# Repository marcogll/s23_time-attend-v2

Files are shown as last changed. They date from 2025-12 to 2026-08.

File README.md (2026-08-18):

<p align="center">
  <a href="https://soul23.mx">
    <picture>
      <source
        media="(prefers-color-scheme: dark)"
        srcset="https://raw.githubusercontent.com/marcogll/mg_data_storage/refs/heads/main/soul23/logo/soul23_logo_wh.png">
      <source
        media="(prefers-color-scheme: light)"
        srcset="https://raw.githubusercontent.com/marcogll/mg_data_storage/refs/heads/main/soul23/logo/soul23_logo_blk.png">
      Soul:23
    </picture>
  </a>
</p>

<h1 align="center">S23 Time Attend V2</h1>

<p align="center">
  Sistema de control de asistencia y jornada — dispositivo IoT basado en ESP32-S3.
</p>

<p align="center">
  
  
  
</p>

---

## Description

Sistema de control de asistencia y jornada en hardware: Time & Attendance IoT device basado en ESP32-S3 con diagrama de conexión (pinout seguro), guía de inicio rápido y carga de firmware.

C++ con PlatformIO/Arduino.

## ⚡️ Características Destacadas

*   **🛡️ Robustez Industrial:**
    *   **NFC Watchdog:** Verificación cada 15s. Si el lector se congela, el sistema realiza un *Hard Reset* físico al módulo RC522 y fuerza la ganancia de antena al máximo.
    *   **Auto-Formato:** Gestión automática del sistema de archivos (`LittleFS`) si se detecta corrupción.
    *   **Anti-Bloqueo:** Uso de `ESP8266WebServer` síncrono y gestión de memoria optimizada (PROGMEM) para evitar reinicios por desbordamiento de pila.

*   **⚙️ Configuración Vía Web (Portal Cautivo):**
    *   No requiere editar código (`secrets.h`) para cambiar WiFi o URLs.
    *   Configura **SSID**, **Password**, **Webhook URL** y **Nombre del Dispositivo** (User-Agent) desde el navegador.

*   **🎮 Controles Físicos y Gestuales:**
    *   **Doble Reset (Double Tap):** Presiona el botón `RST` dos veces rápido para forzar el Modo Configuración sin abrir la carcasa.
    *   **Botón Físico:** Opción de forzar config manteniendo presionado el botón (GPIO 0 / Flash) al arrancar.

---

## 🚀 Guía de Inicio Rápido

### 1. Hardware Requerido
| Componente | Descripción |
| :--- | :--- |
| **NodeMCU v2/v3** | ESP8266 (ESP-12E) |
| **RC522** | Lector NFC (SPI) |
| **OLED 0.96"** | Pantalla SSD1306 (I2C) |
| **Buzzer** | Activo/Pasivo (3.3V) |
| **LED** | Indicador de estado |

### 2. Carga del Firmware
Usa el script automatizado para compilar y subir (requiere `arduino-cli`):
```bash
./compile_and_upload.sh
```

### 3. Configuración Inicial
1.  Al encender por primera vez, el dispositivo creará una red WiFi llamada:
    *   **SSID:** `Soul23`
    *   **Password:** `1234567890`
2.  Conéctate con tu móvil o PC.
3.  Accede a `http://192.168.4.1` en tu navegador.
4.  Ingresa los datos:
    *   **SSID / Password:** Tu red WiFi local.
    *   **Webhook URL:** Endpoint donde recibirás los registros (ej. `https://api.tuempresa.com/asistencia`).
    *   **Nombre del Dispositivo:** Identificador único (se envía como `User-Agent` y en el JSON).
5.  Dale a "Guardar y Reiniciar". ¡Listo!

---

## 🔌 Diagrama de Conexión (Pinout Seguro)

Este pinout evita conflictos con el proceso de arranque (Boot) del ESP8266.

| RC522 | NodeMCU | GPIO | Notas |
| :--- | :--- | :--- | :--- |
| **SDA (SS)** | D8 | GPIO15 | Pull-down interno |
| **SCK** | D5 | GPIO14 | SPI Clock |
| **MOSI** | D7 | GPIO13 | SPI MOSI |
| **MISO** | D6 | GPIO12 | SPI MISO |
| **RST** | D0 | GPIO16 | **CRÍTICO:** Usado para Hard Reset del lector |
| **3.3V** | 3V3 | - | ⚠️ No usar 5V |
| **GND** | GND | - | - |

| Periférico | NodeMCU | GPIO | Notas |
| :--- | :--- | :--- | :--- |
| **OLED SDA** | D2 | GPIO4 | I2C Data |
| **OLED SCL** | D1 | GPIO5 | I2C Clock |
| **Buzzer** | D4 | GPIO2 | Inicializado tarde en setup() |
| **LED / Botón** | D3 | GPIO0 | Flash Button (Pull-up) |

---

## 🧠 Funcionamiento del Watchdog NFC

El lector RC522 es propenso a congelarse por interferencia electromagnética. Este firmware implementa una solución de 3 capas:

1.  **Monitorización:** Cada 15 segundos se consulta la versión del firmware del chip RC522.
2.  **Detección:** Si responde `0x00` o `0xFF`, se considera fallo.
3.  **Recuperación:**
    *   Se pone el pin `RST` (D0) en `LOW` por 50ms (corte de energía lógico).
    *   Se restaura a `HIGH`.
    *   Se re-inicializa la librería y se fuerza la ganancia de antena a `Max (48dB)`.

---

## 📡 Payloads

### Entrada (En Tarjeta NFC)
El tag debe contener un registro NDEF con un JSON válido:
```json
{
  "name": "Ana Lopez",
  "num_emp": "EMP001",
  "sucursal": "Centro",
  "telegram_id": "12345"
}
```

### Salida (Webhook POST)
El dispositivo envía este JSON al servidor:
```json
{
  "uuid": "AbC123XyZ",
  "timestamp": 1703435600,
  "datetime_utc": "2025-12-24T12:00:00Z",
  "date": "2025-12-24",
  "num_empleado": "EMP001",
  "name": "Ana Lopez",
  "branch": "Centro",
  "telegram_id": "12345"
}
```
*Headers:* `User-Agent`: (Nombre configurado en el portal)

---

## 🗺️ Roadmap de Desarrollo

### 📍 Fase 1: Optimización de Transmisión (Corto Plazo)
*   **Payload Base64:** Migrar el formato de envío de JSON plano a su equivalente codificado en **Base64**. Esto mejorará la integridad de los datos y facilitará el manejo de caracteres especiales en el transporte HTTP.

### 📍 Fase 2: Persistencia Offline (Medio Plazo)
*   **Lector MicroSD:** Integración de hardware para almacenamiento local mediante bus SPI.
*   **Sincronización Inteligente:** 
    *   Guardado automático de registros en la MicroSD cuando falla la conexión WiFi/Internet.
    *   Lógica de "Checkpoint": Al recuperar la conexión, el dispositivo verificará cuál fue el último registro recibido por el servidor y enviará en ráfaga los datos pendientes para garantizar **cero pérdida de información**.

### 📍 Fase 3: Modernización de Hardware (Investigación)
*   **Soporte para Apple/Google Wallet:** Investigación y prototipado con lectores que soporten protocolos **NFC VAS (Apple)** y **Smart Tap (Google)**. El objetivo es permitir que los empleados usen sus pases digitales en el móvil en lugar de tarjetas físicas, mejorando la seguridad y la experiencia de usuario.

---

## 📄 Licencia
MIT License.

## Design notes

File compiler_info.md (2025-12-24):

# 🔧 Guía de Compilación y Carga del Firmware

Esta guía te ayudará a compilar, cargar y monitorear el firmware del checador NFC en tu ESP8266 NodeMCU.

---

## 🚀 Método Rápido (Script Automático)

El proyecto incluye un script automatizado que realiza todo el proceso en un solo comando:

```bash
./compile_and_upload.sh
```

### ✨ Características del Script

#### 1. **Verificación de Estado del Dispositivo** 🔌
- ✅ Detecta automáticamente si el ESP8266 está conectado
- ✅ Muestra información detallada del puerto y tipo de placa
- ✅ Detecta automáticamente el puerto si el configurado no está disponible
- ✅ Verifica el estado antes de cada operación crítica

#### 2. **Barras de Progreso y Spinners** 📊
- ✅ Spinner animado durante la compilación
- ✅ Indicadores de progreso durante la carga del firmware
- ✅ Etapas visuales: "Iniciando", "Escribiendo", "Verificando", "Completando"
- ✅ Feedback visual claro en cada paso

#### 3. **Interfaz Mejorada** 🎨
- ✅ Encabezado visual con bordes
- ✅ Colores diferenciados para cada tipo de mensaje
- ✅ Indicadores de progreso paso a paso [1/4], [2/4], etc.
- ✅ Mensajes de error más descriptivos con sugerencias

#### 4. **Detección Automática** 🔍
- ✅ Busca automáticamente dispositivos disponibles si el puerto configurado no funciona
- ✅ Pregunta al usuario si desea usar el puerto detectado
- ✅ Muestra todos los puertos disponibles si no encuentra ninguno

### 📋 Ejemplo de Salida del Script

```
╔══════════════════════════════════════════════════════════╗
║     Checador NFC - Compilación y Carga Automática      ║
╚══════════════════════════════════════════════════════════╝

[0/4] Verificando configuración...
✅ secrets.h encontrado

[1/4] Verificando conexión del dispositivo...
   Puerto configurado: /dev/ttyUSB0
   Estado: ✅ Conectado (NodeMCU 1.0)
   Puerto seleccionado: /dev/ttyUSB0

[2/4] Compilando el sketch...
   FQBN: esp8266:esp8266:nodemcuv2
   Sketch: soul23_time_attendance.ino
   [|] Compilando... |  ← Spinner animado
   [✓] Compilación completada
✅ Compilación exitosa

[3/4] Cargando firmware al dispositivo...
   Puerto: /dev/ttyUSB0
   Estado: ✅ Conectado (NodeMCU 1.0)
   [|] Escribiendo... |  ← Spinner con etapas
   [✓] Carga completada
✅ Firmware cargado exitosamente

[4/4] Abriendo monitor serial...
   Puerto: /dev/ttyUSB0
   Baud rate: 115200
━━━━━━━━━━━━━━━━━━━━━━━━━━━━━━━━━━━━━━━━━━━━━━━━━━━━━━━━━━━━━━━━
   Monitor Serial (Presiona Ctrl+C para salir)
━━━━━━━━━━━━━━━━━━━━━━━━━━━━━━━━━━━━━━━━━━━━━━━━━━━━━━━━━━━━━━━━
```

### 🛠️ Personalización del Script

Puedes modificar estas variables al inicio del script `compile_and_upload.sh`:

```bash
PORT="/dev/ttyUSB0"                    # Puerto del dispositivo
FQBN="esp8266:esp8266:nodemcuv2"       # Tipo de placa
BAUD_RATE="115200"                     # Velocidad del monitor serial
```

---

## 🔧 Comandos Individuales

Si prefieres ejecutar los comandos manualmente o necesitas más control:

### 1. Verificar puertos disponibles

```bash
arduino-cli board list
```

### 2. Compilar el sketch

```bash
arduino-cli compile --fqbn esp8266:esp8266:nodemcuv2 soul23_time_attendance.ino
```

**Nota:** El FQBN `esp8266:esp8266:nodemcuv2` es para NodeMCU 1.0 (ESP-12E Module).

### 3. Cargar al dispositivo

```bash
arduino-cli upload -p /dev/ttyUSB0 --fqbn esp8266:esp8266:nodemcuv2 soul23_time_attendance.ino
```

**⚠️ Importante:** Reemplaza `/dev/ttyUSB0` con el puerto correcto de tu dispositivo (verifica con `arduino-cli board list`)

### 4. Abrir monitor serial

```bash
arduino-cli monitor -p /dev/ttyUSB0 --config baudrate=115200
```

**Para salir del monitor:** Presiona `Ctrl+C`

### 5. Compilar sin cargar (solo verificar errores)

```bash
arduino-cli compile --fqbn esp8266:esp8266:nodemcuv2 soul23_time_attendance.ino
```

### 6. Ver información detallada de compilación

```bash
arduino-cli compile --fqbn esp8266:esp8266:nodemcuv2 --verbose soul23_time_attendance.ino
```

### 7. Limpiar archivos de compilación

```bash
rm -rf build/
```

---

## 📦 Instalación de Dependencias

### Instalar Core de ESP8266

```bash
arduino-cli core install esp8266:esp8266
```

### Instalar Librerías Necesarias

```bash
# Librerías principales
arduino-cli lib install "MFRC522"
arduino-cli lib install "Adafruit SSD1306"
arduino-cli lib install "Adafruit GFX Library"
arduino-cli lib install "ArduinoJson"
arduino-cli lib install "Time"
```

---

## 🔍 Verificar Instalación

### Ver librerías instaladas

```bash
arduino-cli lib list
```

### Ver cores instalados

```bash
arduino-cli core list
```

### Verificar FQBN correcto

```bash
arduino-cli board listall | grep -i nodemcu
```

Salida esperada:
```
NodeMCU 0.9 (ESP-12 Module)                 esp8266:esp8266:nodemcu
NodeMCU 1.0 (ESP-12E Module)                esp8266:esp8266:nodemcuv2
```

---

## 🐛 Solución de Problemas

### Error: "No se encuentra secrets.h"

```bash
cp secrets.h.example secrets.h
# Luego edita secrets.h con tus credenciales
```

### Error: "Puerto no encontrado"

1. Verifica que el ESP8266 esté conectado:
   ```bash
   arduino-cli board list
   ```

2. Si no aparece, verifica permisos:
   ```bash
   sudo usermod -a -G dialout $USER
   ```
   Luego reinicia sesión o ejecuta:
   ```bash
   newgrp dialout
   ```

### Error: "FQBN no válido"

Verifica el modelo exacto de tu NodeMCU y ajusta el FQBN:
- **NodeMCU 1.0 (ESP-12E):** `esp8266:esp8266:nodemcuv2`
- **NodeMCU 0.9:** `esp8266:esp8266:nodemcu`

### Monitor serial no muestra datos

1. Verifica el baud rate (debe ser **115200**)
2. Presiona el botón **RESET** del ESP8266
3. Verifica que el puerto sea correcto
4. Asegúrate de que no haya otro programa usando el puerto serial

### Error durante la carga del firmware

1. **Desconecta el buzzer** temporalmente (desconecta el GND) durante la carga
2. Verifica que no haya otro programa usando el puerto
3. Presiona el botón **RESET** del ESP8266 antes de cargar
4. Si es necesario, mantén presionado el botón **BOOT** mientras cargas

### El script no encuentra el dispositivo

1. El script buscará automáticamente puertos disponibles
2. Si encuentra uno, te preguntará si deseas usarlo
3. Si no encuentra ninguno, verifica:
   - Que el cable USB esté bien conectado
   - Que el driver USB-Serial esté instalado
   - Que tengas permisos para acceder al puerto

---

## 💡 Tips y Mejores Prácticas

### Uso del Script Automático

- El script detecta automáticamente el puerto si el configurado no está disponible
- Los spinners muestran que el proceso está en ejecución
- Los mensajes de error incluyen sugerencias para solucionarlos
- El estado del dispositivo se verifica antes de cada operación crítica

### Desarrollo y Depuración

- **Mantén el monitor serial abierto** mientras pruebas para ver los mensajes de debug
- El código imprime información útil en Serial a 115200 baud
- Si cambias el código, solo necesitas recompilar y cargar (no necesitas cerrar el monitor)
- Para depuración, busca mensajes que empiezan con `--- Checador IOT (Public Version) ---`

### Flujo de Trabajo Recomendado

1. **Primera vez:**
   ```bash
   # Instalar dependencias
   arduino-cli core install esp8266:esp8266
   arduino-cli lib install "MFRC522" "Adafruit SSD1306" "Adafruit GFX Library" "ArduinoJson" "Time"
   
   # Configurar secrets.h
   cp secrets.h.example secrets.h
   # Editar secrets.h con tus credenciales
   
   # Compilar y cargar
   ./compile_and_upload.sh
   ```

2. **Desarrollo iterativo:**
   ```bash
   # Solo necesitas ejecutar el script
   ./compile_and_upload.sh
   ```

3. **Solo verificar compilación:**
   ```bash
   arduino-cli compile --fqbn esp8266:esp8266:nodemcuv2 soul23_time_attendance.ino
   ```

### Optimización

- Si tienes problemas de espacio, puedes limpiar archivos de compilación:
  ```bash
  rm -rf build/
  ```
- Para compilaciones más rápidas, el script ya optimiza el proceso automáticamente

---

## 📝 Resumen de Comandos Rápidos

```bash
# Método rápido (recomendado)
./compile_and_upload.sh

# Comandos individuales
arduino-cli board list                                    # Ver puertos
arduino-cli compile --fqbn esp8266:esp8266:nodemcuv2 soul23_time_attendance.ino
arduino-cli upload -p /dev/ttyUSB0 --fqbn esp8266:esp8266:nodemcuv2 soul23_time_attendance.ino
arduino-cli monitor -p /dev/ttyUSB0 --config baudrate=115200

# Verificación
arduino-cli lib list                                      # Ver librerías
arduino-cli core list                                     # Ver cores
arduino-cli board listall | grep -i nodemcu              # Ver placas disponibles
```

---

## 🎯 Próximos Pasos

Una vez que hayas compilado y cargado el firmware exitosamente:

1. ✅ Verifica que el dispositivo se conecte a WiFi
2. ✅ Revisa el monitor serial para confirmar la sincronización de tiempo
3. ✅ Prueba acercando una tarjeta NFC para verificar la lectura
4. ✅ Verifica que los registros se envíen correctamente al webhook

Para más información sobre el hardware y la configuración, consulta el [README.md](README.md).

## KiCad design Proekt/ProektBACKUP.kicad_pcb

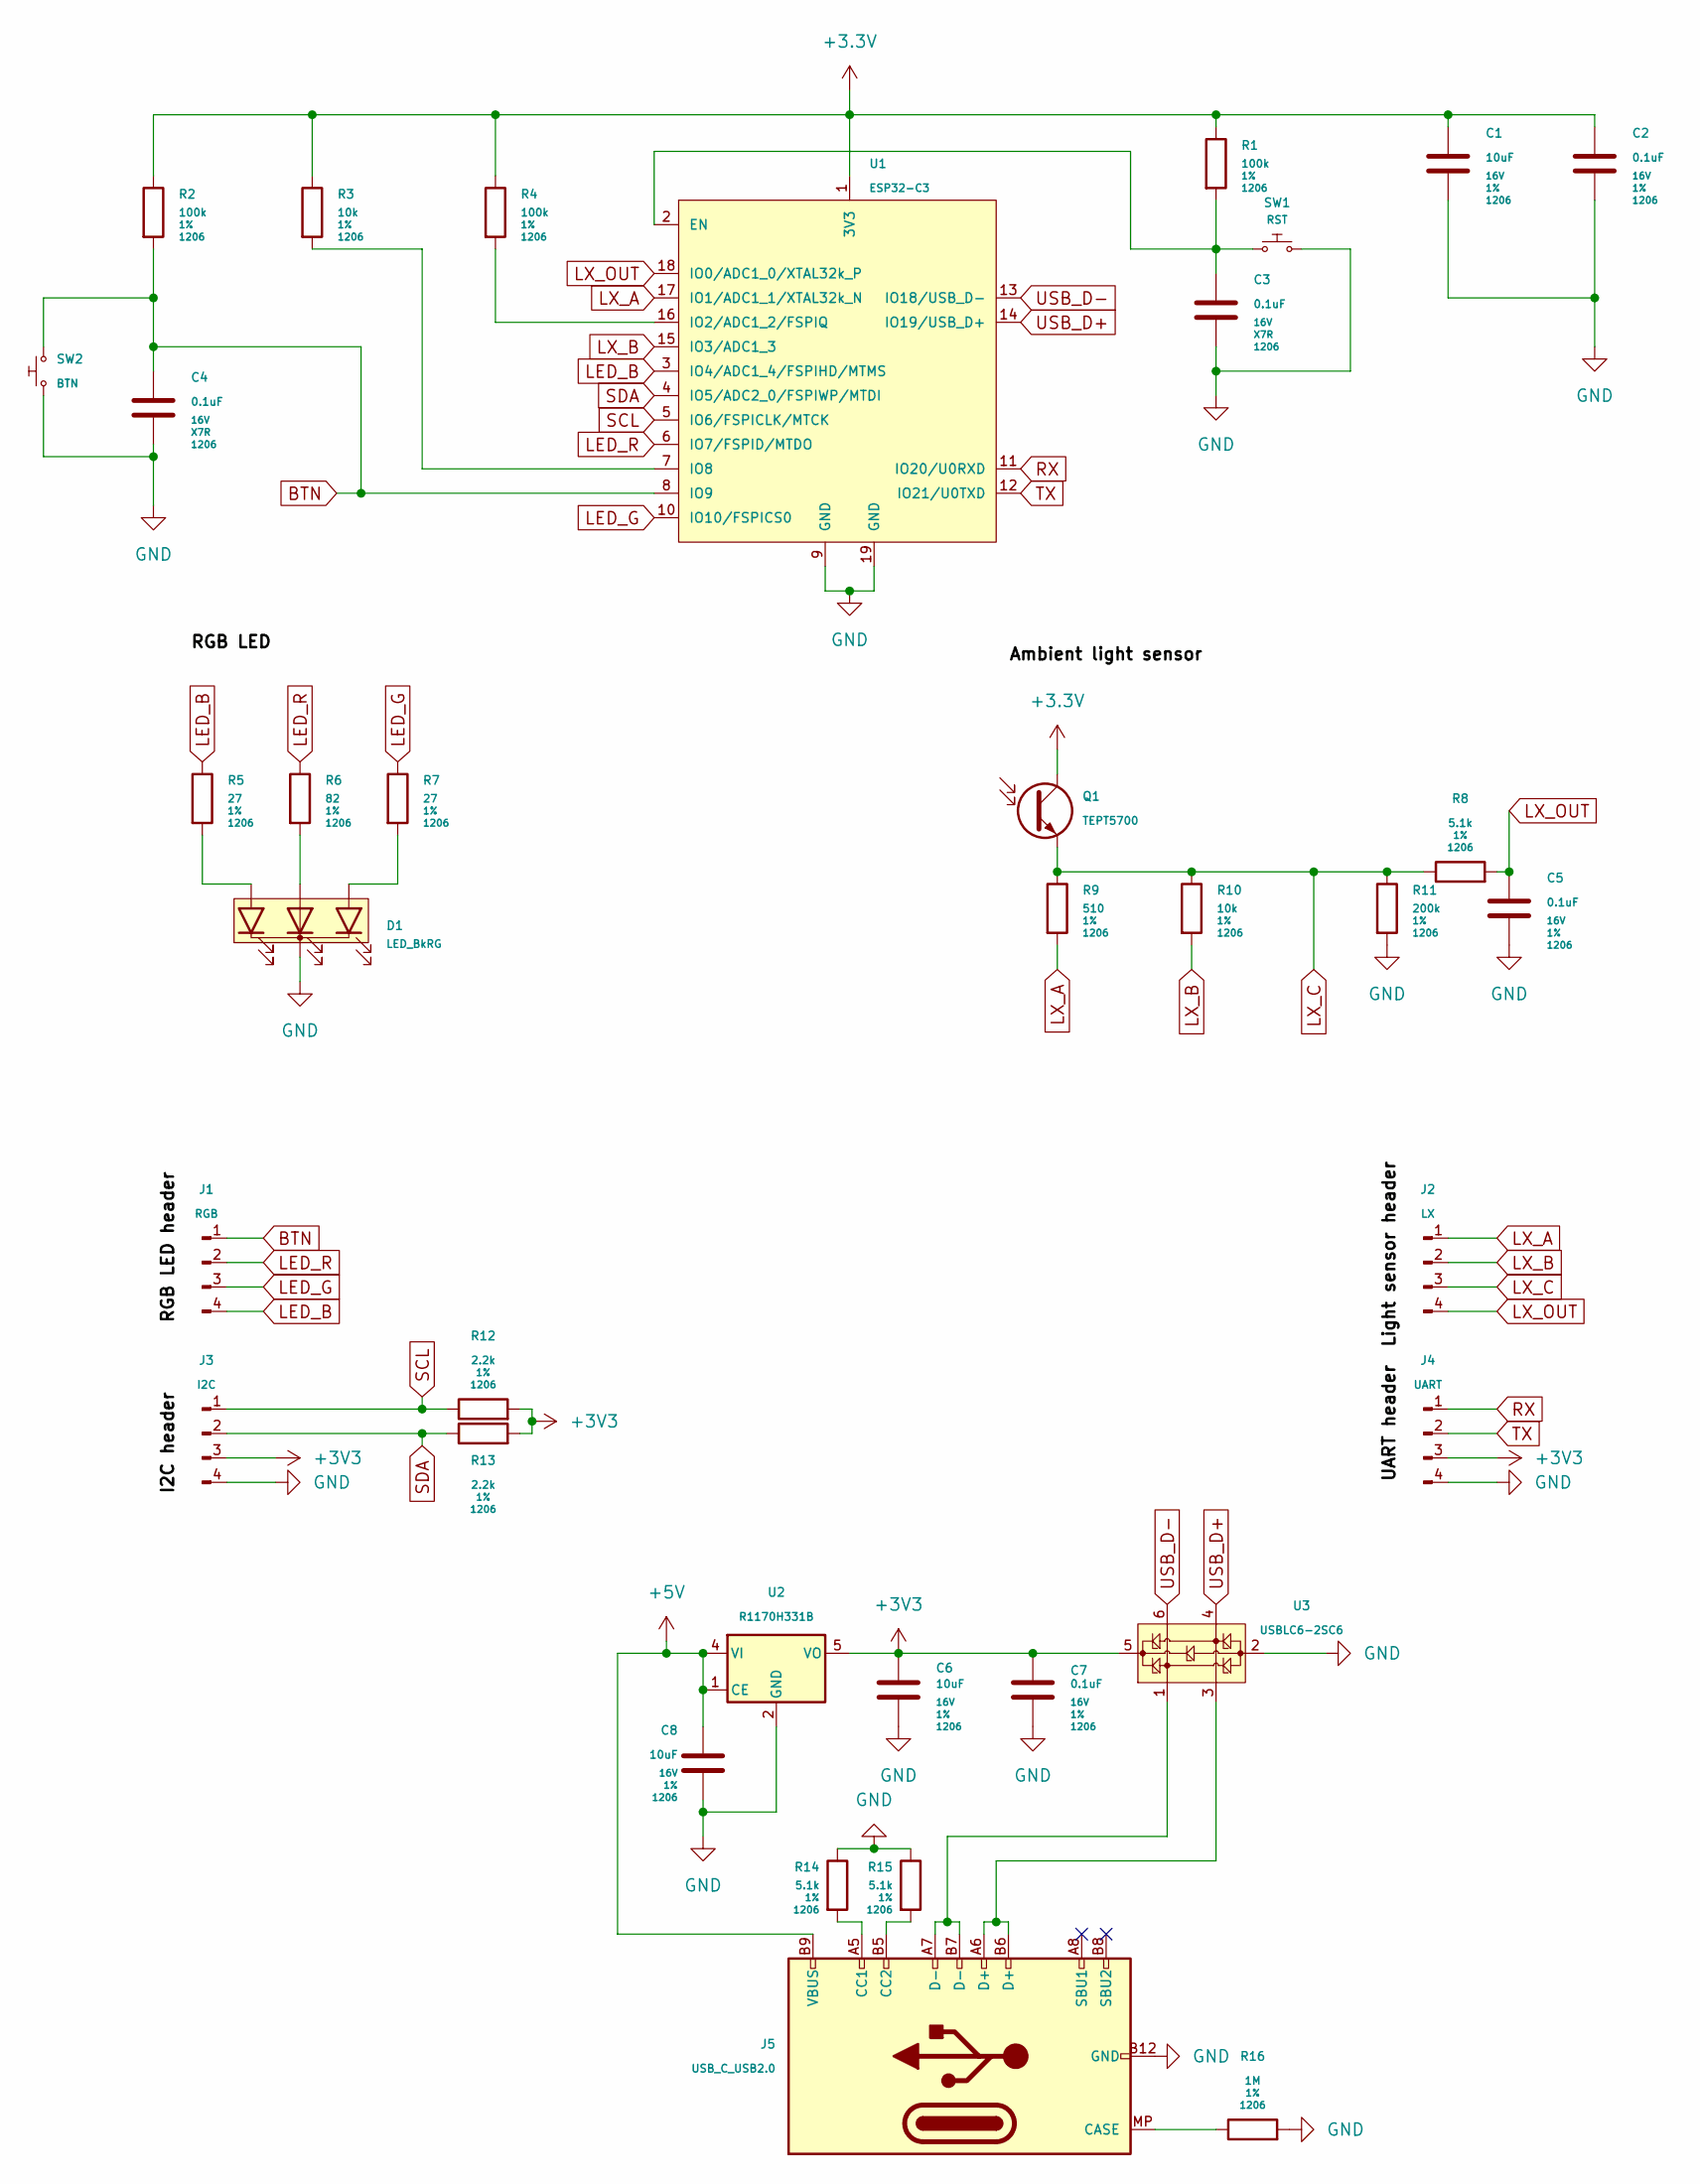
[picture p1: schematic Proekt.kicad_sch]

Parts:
C1, C6, C8: 10uF; C_1206_(3216); Voltage 16V; Tolerance 1%
C2, C5, C7: 0.1uF; C_1206_(3216); Voltage 16V; Tolerance 1%
C3, C4: 0.1uF; C_1206_(3216); Voltage 16V; Tolerance X7R
D1: LED_BkRG; LED_D5.0mm-4_RGB
J1: RGB; PinHeader_1x04_P2.54mm_Vertical
J2: LX; PinHeader_1x04_P2.54mm_Vertical
J3: I2C; PinHeader_1x04_P2.54mm_Vertical
J4: UART; PinHeader_1x04_P2.54mm_Vertical
J5: USB_C_USB2.0; USB-C_MOLEX-216990-0001
Q1: TEPT5700; PT_D5.0mm
R1, R2, R4: 100k; R_1206_(3216); Tolerance 1%
R3, R10: 10k; R_1206_(3216); Tolerance 1%
R5, R7: 27; R_1206_(3216); Tolerance 1%
R6: 82; R_1206_(3216); Tolerance 1%
R8, R14, R15: 5.1k; R_1206_(3216); Tolerance 1%
R9: 510; R_1206_(3216); Tolerance 1%
R11: 200k; R_1206_(3216); Tolerance 1%
R12, R13: 2.2k; R_1206_(3216); Tolerance 1%
R16: 1M; R_1206_(3216); Tolerance 1%
SW1: RST; SW_PUSH_6mm_SMD
SW2: BTN; SW_PUSH_6mm_SMD
U1: ESP32-C3; ESP32-C3-WROOM-02
U2: R1170H331B; SOT-89-5
U3: USBLC6-2SC6; SOT-23-6

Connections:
+5V: C8.1, J5.A4 (VBUS), J5.A9 (VBUS), J5.B4 (VBUS), J5.B9 (VBUS), U2.1 (CE), U2.4 (VI)
BTN: C4.1, J1.1, R2.2, SW2.COM, U1.8 (IO9)
GND: C1.2, C2.2, C3.1, C4.2, C5.2, C6.2, C7.2, C8.2, D1.K, J3.4, J4.4, J5.A1 (GND), J5.A12 (GND), J5.B1 (GND), J5.B12 (GND), R11.2, R14.1, R15.1, R16.2, SW1.COM, SW2.NO, U1.9 (GND), U1.19 (GND), U2.2 (GND), U3.2 (GND)
LED_B: J1.4, R5.1, U1.3 (IO4/ADC1_4/FSPIHD/MTMS)
LED_G: J1.3, R7.1, U1.10 (IO10/FSPICS0)
LED_R: J1.2, R6.1, U1.6 (IO7/FSPID/MTDO)
LX_A: J2.1, R9.2, U1.17 (IO1/ADC1_1/XTAL32k_N)
LX_B: J2.2, R10.2, U1.15 (IO3/ADC1_3)
LX_C: J2.3, Q1.E, R8.1, R9.1, R10.1, R11.1
LX_OUT: C5.1, J2.4, R8.2, U1.18 (IO0/ADC1_0/XTAL32k_P)
unnamed: D1.Ab (Ablue), R5.2
unnamed: D1.Ag (Agreen), R7.2
unnamed: D1.Ar (Ared), R6.2
unnamed: J5.MP (CASE), R16.1
unnamed: J5.A5 (CC1), R14.2
unnamed: J5.B5 (CC2), R15.2
unnamed: J5.A6 (D+), J5.B6 (D+), U3.3 (I/O2)
unnamed: J5.A7 (D-), J5.B7 (D-), U3.1 (I/O1)
unnamed: C3.2, R1.2, SW1.NO, U1.2 (EN)
unnamed: R4.2, U1.16 (IO2/ADC1_2/FSPIQ)
unnamed: R3.2, U1.7 (IO8)
RX: J4.1, U1.11 (IO20/U0RXD)
SCL: J3.1, R12.1, U1.5 (IO6/FSPICLK/MTCK)
SDA: J3.2, R13.1, U1.4 (IO5/ADC2_0/FSPIWP/MTDI)
TX: J4.2, U1.12 (IO21/U0TXD)
USB_D+: U1.14 (IO19/USB_D+), U3.4 (I/O2)
USB_D-: U1.13 (IO18/USB_D-), U3.6 (I/O1)

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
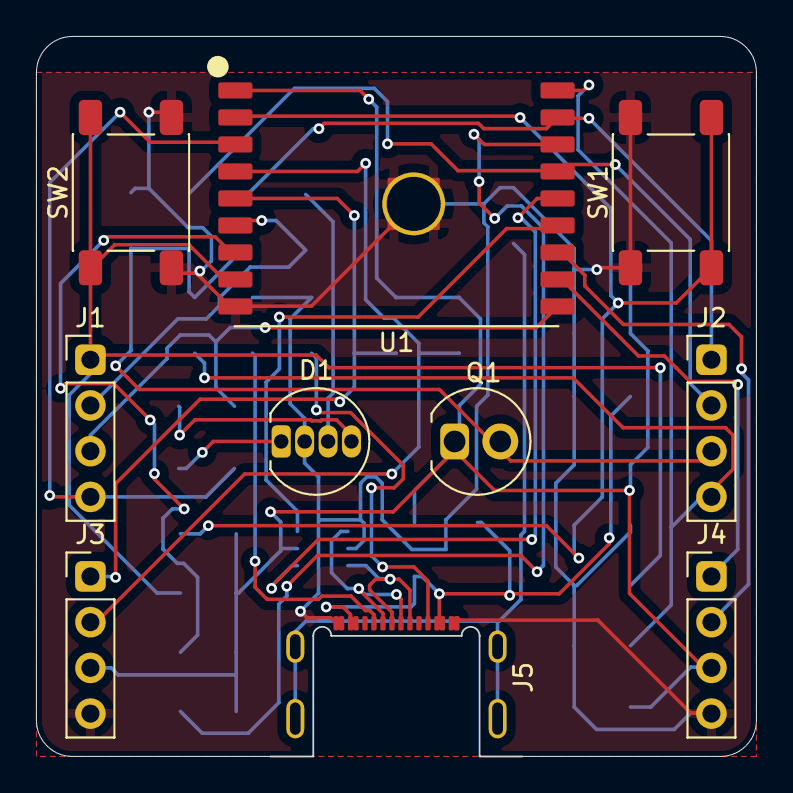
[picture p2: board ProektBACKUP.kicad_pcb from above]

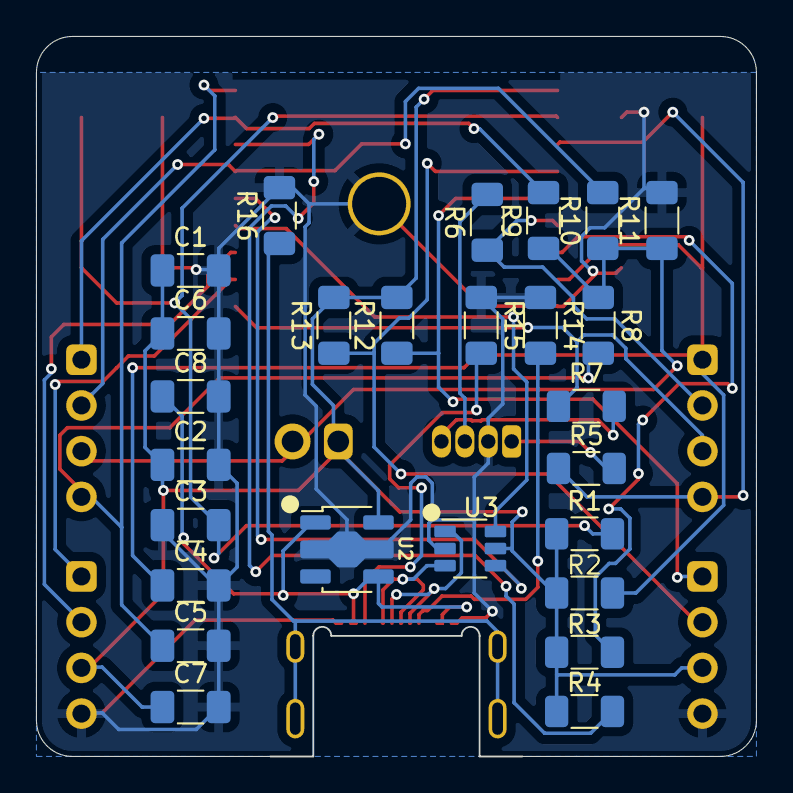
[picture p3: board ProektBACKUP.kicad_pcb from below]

Board: 2 copper layers, 40.0 x 40.0 mm, 36 parts (26 on the bottom side), 28 nets.

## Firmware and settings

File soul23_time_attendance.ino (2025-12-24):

#include <SPI.h>
#include <MFRC522.h>
#include <ESP8266WiFi.h>
#include <ESP8266HTTPClient.h>
#include <WiFiClientSecure.h>
#include <ArduinoJson.h>
#include <Wire.h>
#include <Adafruit_GFX.h>
#include <Adafruit_SSD1306.h>
#include <TimeLib.h> // Requiere instalar: arduino-cli lib install "Time"
#include <ESP8266WebServer.h>
#include <DNSServer.h>

#include "Config.h"

// Constantes globales de configuración
const char* timeServerUrl = "https://worldtimeapi.org/api/ip";
// const char* DEVICE_NAME = "Checador_Oficina_1"; // Eliminado, ahora es dinámico
const long timeZoneOffset = -21600;

// Intervalo de resincronización del reloj (1 hora)
const unsigned long syncInterval = 3600000; 

// ==========================================
// 🔌 PINES SEGUROS (NO INTERFIEREN CON BOOT)
// ==========================================
#define SS_PIN  D8  // GPIO 15
#define RST_PIN D0  // GPIO 16
#define OLED_SDA D2
#define OLED_SCL D1
#define LED_PIN  D3  // LED de estatus (GPIO 0) - Inicializado con pull-up para evitar problemas de boot
#define BUZZER_PIN D4 // Buzzer (GPIO 2) - ⚠️ IMPORTANTE: Inicializado MUY TARDE en setup() para evitar problemas de boot

MFRC522 mfrc522(SS_PIN, RST_PIN);

#define SCREEN_WIDTH 128
#define SCREEN_HEIGHT 64
Adafruit_SSD1306 display(SCREEN_WIDTH, SCREEN_HEIGHT, &Wire, -1);

// Variables para el modo configuración
Config config;
ESP8266WebServer *server = nullptr;
DNSServer *dnsServer = nullptr;
bool configurationMode = false;
bool shouldRestart = false;

// Variables de control
unsigned long lastSyncTime = 0;
int lastMinuteDisplayed = -1;
bool hasError = false;
unsigned long lastBlinkTime = 0;
bool ledState = LOW;

// Control del Watchdog del Lector NFC
const unsigned long nfcCheckInterval = 15000; // 15 segundos para detección rápida de fallos
unsigned long lastNfcCheck = 0;


// ==========================================
// 📝 DECLARACIONES DE FUNCIONES
// ==========================================
void checkAndResetNFC();
void showStatus(String line1, String line2);
void syncTimeWithServer();
bool sendToWebhook(String uid, String name, String num_emp, String sucursal, String telegram_id);
void showClockScreen();
String getFormattedTime();
bool readCardData(byte *data, byte *length);
void processTag();
String generateUUID(byte length);
String getISO8601DateTime(time_t t);
String getFormattedDate();
void beep(int times, int duration);
void alarmSound();
void silenceBuzzer();
void updateStatusLED();
void scanI2C();
void startConfigurationMode();

// ==========================================
// 🚀 SETUP
// ==========================================
void setup() {
  Serial.println("\n--- Iniciando setup ---");
  // ⚠️ CRÍTICO: Inicializar GPIO 2 (BUZZER) PRIMERO para evitar ruido durante boot
  // GPIO 2 tiene pull-up interno que puede causar problemas con buzzer pasivo
  // Configurarlo como INPUT sin pull-up/pull-down para evitar interferencia
  pinMode(BUZZER_PIN, INPUT); // INPUT sin pull para evitar ruido durante boot
  delay(10); // Pequeña pausa para estabilizar
  
  // ⚠️ INICIALIZAR GPIO 0 (LED) CON PULL-UP para evitar problemas de boot
  // Si GPIO 0 está LOW durante boot, el ESP8266 entra en modo programación
  pinMode(LED_PIN, INPUT_PULLUP); // Primero como INPUT con pull-up interno
  delay(10); // Pequeña pausa para estabilizar
  
  Serial.begin(115200);
  delay(100);

  WiFi.persistent(false); // Evita la reconexión automática que causa conflictos

  Serial.println("\n\n--- Checador IOT (Public Version) ---");
  
  randomSeed(analogRead(A0));

  SPI.begin();
  Wire.begin(OLED_SDA, OLED_SCL);

  scanI2C();
  mfrc522.PCD_Init();
  mfrc522.PCD_DumpVersionToSerial();
  mfrc522.PCD_SetAntennaGain(mfrc522.RxGain_max); // 🚀 Maxima ganancia antena

  if(!display.begin(SSD1306_SWITCHCAPVCC, 0x3C)) {
    Serial.println(F("Intentando dirección OLED 0x3D..."));
    if(!display.begin(SSD1306_SWITCHCAPVCC, 0x3D)) {
      Serial.println(F("Error: No se encuentra OLED"));
      sos();
    }
  }
  display.clearDisplay();
  display.setTextColor(WHITE);
  display.dim(false);
  Serial.println("OLED inicializado y configurado.");

  if (!LittleFS.begin()) {
    Serial.println("LittleFS mount failed. Formatting...");
    if (LittleFS.format()) {
      Serial.println("LittleFS formatted successfully");
      if (LittleFS.begin()) {
        Serial.println("LittleFS mounted after format");
      } else {
        Serial.println("LittleFS mount failed after format");
      }
    } else {
      Serial.println("LittleFS format failed");
    }
  } else {
    Serial.println("LittleFS mounted successfully");
  }
  // --- Lógica de Doble Reset (Double Tap) ---
  uint32_t rtcMagic = 0;
  ESP.rtcUserMemoryRead(0, &rtcMagic, sizeof(rtcMagic));
  bool doubleResetDetected = (rtcMagic == 0x1A2B3C4D);

  // Armar el detector para el siguiente reset (se desarmará en loop después de 3s)
  rtcMagic = 0x1A2B3C4D;
  ESP.rtcUserMemoryWrite(0, &rtcMagic, sizeof(rtcMagic));

  // Verificar botón físico (Flash/D3) O Doble Reset
  bool forceConfigMode = (digitalRead(LED_PIN) == LOW) || doubleResetDetected;
  
  pinMode(LED_PIN, OUTPUT);
  digitalWrite(LED_PIN, LOW);

  Serial.print("Modo Config forzado: ");
  if (digitalRead(LED_PIN) == LOW) Serial.print("BOTON ");
  if (doubleResetDetected) Serial.print("DOBLE_RESET ");
  Serial.println(forceConfigMode ? "(SI)" : "(NO)");

  bool configLoaded = loadConfig(config);
  Serial.print("Configuración cargada exitosamente: ");
  Serial.println(configLoaded ? "Sí" : "No");

  if (configLoaded && !forceConfigMode) {
    showStatus("CONECTANDO", "WIFI...");
    WiFi.mode(WIFI_STA);
    WiFi.begin(config.ssid, config.password);

    int timeout = 0;
    while (WiFi.status() != WL_CONNECTED && timeout < 60) {
      delay(500); Serial.print("."); timeout++;
    }

    if (WiFi.status() == WL_CONNECTED) {
      showStatus("WIFI", "OK");
      delay(1000);
      configurationMode = false;
    } else {
      showStatus("ERROR WIFI", "MODO CONFIG");
      delay(2000);
      configurationMode = true;
    }
  } else {
    showStatus("HOLA!", "MODO CONFIG");
    delay(2000);
    configurationMode = true;
  }
  
  if (configurationMode) {
    startConfigurationMode();
  } else {
    syncTimeWithServer();
    Serial.println("Sistema Listo.");

    delay(100);
    pinMode(BUZZER_PIN, OUTPUT);
    digitalWrite(BUZZER_PIN, LOW);
    delay(50);
    digitalWrite(BUZZER_PIN, LOW);
    delay(10);
    digitalWrite(BUZZER_PIN, LOW);

    blinkLed(5, 200);
    digitalWrite(LED_PIN, LOW);
    silenceBuzzer();
  }
}

// ==========================================
// 🔄 LOOP PRINCIPAL
// ==========================================
void loop() {
  // Desarmar Doble Reset después de 3 segundos de funcionamiento estable
  static bool drDisarmed = false;
  if (!drDisarmed && millis() > 3000) {
      uint32_t rtcMagic = 0;
      ESP.rtcUserMemoryWrite(0, &rtcMagic, sizeof(rtcMagic));
      drDisarmed = true;
      // Serial.println("Double Reset: Desarmado"); // Opcional para debug
  }

  if (shouldRestart) {
    Serial.println(F("Reiniciando sistema..."));
    delay(2000);
    ESP.restart();
  }

  if (configurationMode) {
    if (dnsServer) dnsServer->processNextRequest();
    if (server) server->handleClient();
    delay(10);
  } else {
    checkAndResetNFC();

    if (timeStatus() == timeNotSet || (millis() - lastSyncTime > syncInterval)) {
      syncTimeWithServer();
    }

    if (minute() != lastMinuteDisplayed) {
      showClockScreen();
      lastMinuteDisplayed = minute();
    }

    if (mfrc522.PICC_IsNewCardPresent() && mfrc522.PICC_ReadCardSerial()) {
      processTag();
      lastMinuteDisplayed = -1;
    }

    silenceBuzzer();
    delay(50);
  }
}

// ==========================================
// 📋 LÓGICA DE PROCESAMIENTO
// ==========================================
void processTag() {
  String uid = "";
  for (byte i = 0; i < mfrc522.uid.size; i++) {
     uid += (mfrc522.uid.uidByte[i] < 0x10 ? "0" : "");
     uid += String(mfrc522.uid.uidByte[i], HEX);
  }
  uid.toUpperCase();

  byte buffer[128]; 
  byte bufferSize = sizeof(buffer);
  
  if (readCardData(buffer, &bufferSize)) {
    int jsonStart = -1;
    for (int i = 0; i < bufferSize; i++) { if (buffer[i] == '{') { jsonStart = i; break; } }

    if (jsonStart != -1) {
      DynamicJsonDocument docCard(512);
      DeserializationError error = deserializeJson(docCard, (const char*)(buffer + jsonStart));

      if (error) {
        showStatus("ERROR", "JSON ILEGIBLE");
        signalTemporaryError();
      } else {
        String name = docCard["name"];
        String num_emp = docCard["num_emp"];
        String sucursal = docCard["sucursal"];
        String telegram_id = docCard["telegram_id"];
        
        sendToWebhook(uid, name, num_emp, sucursal, telegram_id);
      }
    } else {
      showStatus("ERROR", "SIN JSON");
      signalTemporaryError();
    }
  } else {
    showStatus("ERROR", "LECTURA FALLO");
    signalTemporaryError();
  }

  mfrc522.PICC_HaltA();
  mfrc522.PCD_StopCrypto1();
  // El delay y el apagado del LED se manejan ahora en las funciones de señalización
}

// ==========================================
// 🚨 WATCHDOG DEL LECTOR NFC
// ==========================================
/**
 * @brief Verifica el estado del lector NFC y lo reinicia si no responde.
 * 
 * Se ejecuta periódicamente según 'nfcCheckInterval'. Lee el registro de versión
 * del chip MFRC522. Si devuelve 0x00 o 0xFF, asume que está colgado e intenta
 * reinicializarlo mediante un HARD RESET físico (Pin RST).
 */
void checkAndResetNFC() {
  if (millis() - lastNfcCheck > nfcCheckInterval) {
    // 1. Heartbeat check: Read Firmware Version
    byte v = mfrc522.PCD_ReadRegister(MFRC522::VersionReg);

    // Si la versión es 0x00 o 0xFF, la comunicación SPI o el módulo fallaron
    if (v == 0x00 || v == 0xFF) {
      Serial.println(F("NFC Watchdog: Lector NO responde. Ejecutando HARD RESET..."));

      // 2. Hard Reset Sequence (Physical Pin Toggle)
      // Forzamos el pin RST a LOW para reiniciar el chip físicamente
      pinMode(RST_PIN, OUTPUT);
      digitalWrite(RST_PIN, LOW);
      delay(50); // Mantener reset
      digitalWrite(RST_PIN, HIGH);
      delay(50); // Esperar a que el chip despierte

      // 3. Re-Inicializar Librería
      mfrc522.PCD_Init();
      delay(10);

      // 4. Boost Sensitivity (Max Gain) - Importante para estabilidad
      mfrc522.PCD_SetAntennaGain(mfrc522.RxGain_max);

      // 5. Verificar recuperación
      byte v_new = mfrc522.PCD_ReadRegister(MFRC522::VersionReg);
      if (v_new == 0x00 || v_new == 0xFF) {
         Serial.println(F("NFC Watchdog: FALLO. El lector sigue sin responder."));
      } else {
         Serial.print(F("NFC Watchdog: RECUPERADO. Versión: 0x"));
         Serial.println(v_new, HEX);
      }
    } 
    // Si responde bien, no hacemos nada para no interrumpir el flujo normal
    
    lastNfcCheck = millis();
  }
}

// ==========================================
// ☁️ RED Y LECTURA DE TARJETA
// ==========================================
/**
 * @brief Lee los datos almacenados en los bloques de la tarjeta MIFARE.
 * 
 * Intenta autenticarse con la clave por defecto (NFC Forum Key) y leer
 * los bloques 4 a 12 de la tarjeta.
 * 
 * @param data Puntero al buffer donde se guardarán los datos leídos.
 * @param length Puntero al tamaño del buffer (se actualiza con bytes leídos).
 * @return true Si la lectura fue exitosa.
 * @return false Si hubo error de autenticación o lectura.
 */
bool readCardData(byte *data, byte *length) {
  MFRC522::MIFARE_Key key;
  byte nfcForumKey[6] = {0xD3, 0xF7, 0xD3, 0xF7, 0xD3, 0xF7};
  memcpy(key.keyByte, nfcForumKey, 6);

  MFRC522::StatusCode status = mfrc522.PCD_Authenticate(MFRC522::PICC_CMD_MF_AUTH_KEY_A, 4, &key, &(mfrc522.uid));
  if (status != MFRC522::STATUS_OK) { return false; }
  
  delay(5);

  byte readBlock[18];
  byte index = 0;
  for (byte block = 4; block < 12; block++) {
    if (block % 4 == 3) {
      status = mfrc522.PCD_Authenticate(MFRC522::PICC_CMD_MF_AUTH_KEY_A, block + 1, &key, &(mfrc522.uid));
      if (status != MFRC522::STATUS_OK) break;
      continue;
    }
    byte size = sizeof(readBlock);
    status = mfrc522.MIFARE_Read(block, readBlock, &size);
    if (status != MFRC522::STATUS_OK) break;
    memcpy(&data[index], readBlock, 16);
    index += 16;
  }
  *length = index;
  return index > 0;
}

/**
 * @brief Sincroniza la hora interna del ESP8266 con un servidor NTP/API externo.
 * 
 * Realiza una petición HTTP GET a 'timeServerUrl' (WorldTimeAPI).
 * Parsea el JSON de respuesta y establece la hora del sistema usando 'TimeLib'.
 */
void syncTimeWithServer() {
  if (WiFi.status() != WL_CONNECTED) return;
  std::unique_ptr<WiFiClientSecure> client(new WiFiClientSecure);
  client->setInsecure();
  HTTPClient http;
  if (http.begin(*client, timeServerUrl)) {
    http.setTimeout(10000); // Timeout de 10 segundos para evitar resets por watchdog
    http.setUserAgent(config.deviceName);
    int httpCode = http.GET();
    if (httpCode == HTTP_CODE_OK) {
      DynamicJsonDocument doc(1024);
      deserializeJson(doc, http.getString());
      // Ajuste para el servidor de ejemplo worldtimeapi.org
      setTime(doc["unixtime"].as<unsigned long>() + timeZoneOffset); 
      lastSyncTime = millis();
    }
    http.end();
  }
}

/**
 * @brief Envía el registro de asistencia al Webhook configurado.
 * 
 * Construye un JSON con los datos del empleado y la tarjeta, y lo envía
 * mediante una petición HTTP POST segura (HTTPS).
 * 
 * @param uid UID de la tarjeta leída.
 * @param name Nombre del empleado.
 * @param num_emp Número de empleado.
 * @param sucursal Sucursal asignada.
 * @param telegram_id ID de Telegram para notificaciones.
 * @return true Si el envío fue exitoso (HTTP 2xx).
 * @return false Si hubo error en la conexión o respuesta.
 */
bool sendToWebhook(String uid, String name, String num_emp, String sucursal, String telegram_id) {
  if (timeStatus() == timeNotSet) {
    showStatus("ERROR", "SIN HORA");
    signalTemporaryError();
    return false;
  }
  
  std::unique_ptr<WiFiClientSecure> client(new WiFiClientSecure);
  client->setInsecure();
  HTTPClient http;
  
  unsigned long utcTimestamp = now() - timeZoneOffset;
  String uuid = generateUUID(11);
  String date = getFormattedDate();
  String datetime_utc = getISO8601DateTime(utcTimestamp);

  showStatus("ENVIANDO", "REGISTRO...");

  Serial.print("Webhook URL: "); Serial.println(config.webhookUrl);

  if (http.begin(*client, config.webhookUrl)) {
    http.setTimeout(15000); // Aumentar timeout a 15s
    http.setUserAgent(config.deviceName);
    http.addHeader("Content-Type", "application/json");

    DynamicJsonDocument doc(1024);
    JsonArray array = doc.to<JsonArray>();

    JsonObject obj = array.createNestedObject();
    obj["uuid"] = uuid;
    obj["timestamp"] = utcTimestamp;
    obj["datetime_utc"] = datetime_utc;
    obj["date"] = date;
    obj["num_empleado"] = num_emp;
    obj["name"] = name;
    obj["branch"] = sucursal;
    obj["telegram_id"] = telegram_id;

    String jsonPayload;
    serializeJson(doc, jsonPayload);
    Serial.print("Payload: "); Serial.println(jsonPayload); // Debug payload
    
    int httpResponseCode = http.POST(jsonPayload);
    Serial.print("HTTP Code: "); Serial.println(httpResponseCode); // Debug code

    if (httpResponseCode > 0) {
        String response = http.getString();
        Serial.println("Respuesta: " + response);
    } else {
        Serial.print("Error HTTP: ");
        Serial.println(http.errorToString(httpResponseCode));
    }

    if (httpResponseCode >= 200 && httpResponseCode < 300) {
      showStatus("HOLA :)", name);
      http.end();
      blinkLed(5, 200); // Éxito - Parpadeo de 5 veces (mismo comportamiento que boot)
      return true;
    } else {
      showStatus("ERROR", "AL ENVIAR");
      http.end();
      signalTemporaryError();
      return false;
    }
  }
  signalTemporaryError();
  return false;
}

// ==========================================
// 🔊 BUZZER Y LEDS
// ==========================================

void signalTemporaryError() {
  alarmSound();
  digitalWrite(LED_PIN, HIGH);
  delay(5000);
  digitalWrite(LED_PIN, LOW);
}

void blinkLed(int times, int duration) {
  for (int i = 0; i < times; i++) {
    digitalWrite(LED_PIN, HIGH);
    delay(duration);
    digitalWrite(LED_PIN, LOW);
    if (i < times - 1) delay(duration);
  }
}

void morseDot() {
  digitalWrite(LED_PIN, HIGH);
  delay(250);
  digitalWrite(LED_PIN, LOW);
  delay(250);
}

void morseDash() {
  digitalWrite(LED_PIN, HIGH);
  delay(750);
  digitalWrite(LED_PIN, LOW);
  delay(250);
}

void sos() {
  while(true) { // Bucle infinito para S.O.S.
    // SOS con la luz: ... --- ... (3 segundos)
    morseDot(); morseDot(); morseDot();
    delay(500);
    morseDash(); morseDash(); morseDash();
    delay(500);
    morseDot(); morseDot(); morseDot();
    delay(3000); // 3 segundos de SOS
    delay(10000); // Esperar 10 segundos antes de repetir
  }
}

void beep(int times, int duration) {
  // Asegurar que el pin esté configurado (por si se llama antes del setup completo)
  static bool buzzerInitialized = false;
  if (!buzzerInitialized) {
    pinMode(BUZZER_PIN, OUTPUT);
    digitalWrite(BUZZER_PIN, LOW);
    buzzerInitialized = true;
  }
  
  for (int i = 0; i < times; i++) {
    digitalWrite(BUZZER_PIN, HIGH);
    delay(duration);
    digitalWrite(BUZZER_PIN, LOW);
    if (i < times - 1) delay(duration / 2);
  }
  
  // Asegurar que el buzzer quede silenciado después de cada beep
  digitalWrite(BUZZER_PIN, LOW);
  delay(10); // Pequeña pausa para estabilizar
}

void alarmSound() {
  beep(3, 150); // 3 beeps cortos y rápidos para el error
  silenceBuzzer(); // Asegurar que quede silenciado después del error
}

void silenceBuzzer() {
  // Función para asegurar que el buzzer esté completamente silenciado
  // Útil para evitar ruido o interferencia electromagnética
  // Asegurar que el pin esté configurado como OUTPUT y en LOW
  pinMode(BUZZER_PIN, OUTPUT);
  digitalWrite(BUZZER_PIN, LOW);
}

// ==========================================
// 🖥️ PANTALLA Y UTILIDADES
// ==========================================
String generateUUID(byte length) {
  String randomString = "";
  const char charset[] = "ABCDEFGHIJKLMNOPQRSTUVWXYZabcdefghijklmnopqrstuvwxyz0123456789";
  for (byte i = 0; i < length; i++) {
    randomString += charset[random(sizeof(charset) - 1)];
  }
  return randomString;
}

String getISO8601DateTime(time_t t) {
  char buff[21];
  sprintf(buff, "%04d-%02d-%02dT%02d:%02d:%02dZ",
    year(t), month(t), day(t), hour(t), minute(t), second(t));
  return String(buff);
}

String getFormattedDate() {
  String dateStr = String(year()) + "-";
  if (month() < 10) dateStr += "0"; dateStr += String(month());
  dateStr += "-";
  if (day() < 10) dateStr += "0"; dateStr += String(day());
  return dateStr;
}

String getFormattedTime() {
  String timeStr = "";
  int h = hour(); int m = minute(); String ampm = "AM";
  if (h >= 12) { ampm = "PM"; if (h > 12) h -= 12; }
  if (h == 0) h = 12;
  if (h < 10) timeStr += " "; timeStr += String(h); timeStr += ":";
  if (m < 10) timeStr += "0"; timeStr += String(m); timeStr += " " + ampm;
  return timeStr;
}

void showClockScreen() {
  display.clearDisplay();
  display.setTextSize(1); display.setCursor(0, 0); display.println(F("CHECADOR"));
  display.setTextSize(2); display.setCursor(10, 25); 
  if (timeStatus() != timeNotSet) { display.println(getFormattedTime()); }
  else { display.println("--:--"); }
  display.setTextSize(1); display.setCursor(0, 55); display.println(F("ACERQUE TARJETA..."));
  display.display();
}

void showStatus(String line1, String line2) {
  display.clearDisplay();
  display.setTextSize(2); display.setCursor(0, 10); display.println(line1);
  if(line2.length() > 8) display.setTextSize(1); else display.setTextSize(2);
  display.setCursor(0, 35); display.println(line2);
  display.display();
}

void scanI2C() {
  byte error, address;
  int nDevices = 0;
  Serial.println("Dispositivos I2C encontrados:");
  for (address = 1; address < 127; address++) {
    Wire.beginTransmission(address);
    error = Wire.endTransmission();
    if (error == 0) {
      Serial.print("Encontrado en 0x");
      if (address < 16) Serial.print("0");
      Serial.println(address, HEX);
      nDevices++;
    } else if (error == 4) {
      Serial.print("Error desconocido en 0x");
      if (address < 16) Serial.print("0");
      Serial.println(address, HEX);
    }
  }
  if (nDevices == 0) Serial.println("Ningún dispositivo I2C encontrado");
  else Serial.println("Escaneo terminado");
}

// ==========================================
// 🌐 MODO CONFIGURACIÓN WEB
// ==========================================
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

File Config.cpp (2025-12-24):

#include "Config.h"

void saveConfig(const Config& config) {
  Serial.println("Guardando configuración...");
  DynamicJsonDocument doc(512);
  doc["ssid"] = config.ssid;
  doc["password"] = config.password;
  doc["webhookUrl"] = config.webhookUrl;
  doc["deviceName"] = config.deviceName;

  File configFile = LittleFS.open("/config.json", "w");
  if (!configFile) {
    Serial.println("Error: No se pudo abrir el archivo de configuración para escritura.");
    return;
  }

  serializeJson(doc, configFile);
  configFile.close();
  Serial.println("Configuración guardada exitosamente.");
}

bool loadConfig(Config& config) {
  Serial.println("Intentando cargar configuración...");
  if (LittleFS.exists("/config.json")) {
    Serial.println("Archivo 'config.json' encontrado.");
    File configFile = LittleFS.open("/config.json", "r");
    if (configFile) {
      String fileContent = configFile.readString();
      Serial.println("Contenido del archivo: " + fileContent);

      DynamicJsonDocument doc(512);
      DeserializationError error = deserializeJson(doc, fileContent);

      if (!error) {
        Serial.println("JSON parseado correctamente.");
        strlcpy(config.ssid, doc["ssid"], sizeof(config.ssid));
        strlcpy(config.password, doc["password"], sizeof(config.password));
        strlcpy(config.webhookUrl, doc["webhookUrl"], sizeof(config.webhookUrl));
        strlcpy(config.deviceName, doc["deviceName"] | "Checador_Generico", sizeof(config.deviceName));

        Serial.println("SSID cargado: " + String(config.ssid));
        Serial.println("Webhook URL cargado: " + String(config.webhookUrl));
        Serial.println("Device Name cargado: " + String(config.deviceName));

        configFile.close();
        return true;
      } else {
        Serial.print("Error al parsear JSON: ");
        Serial.println(error.c_str());
      }
      configFile.close();
    } else {
        Serial.println("Error: No se pudo abrir el archivo de configuración para lectura.");
    }
  } else {
    Serial.println("No se encontró el archivo 'config.json'.");
  }
  return false;
}
